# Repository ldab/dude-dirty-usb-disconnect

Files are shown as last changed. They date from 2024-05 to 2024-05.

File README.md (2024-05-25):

# dude-dirty-usb-disconnect







<p align="center">
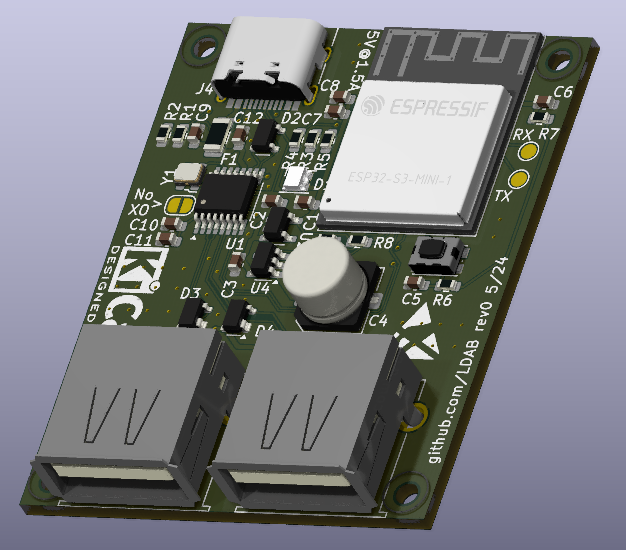
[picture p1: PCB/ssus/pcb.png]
  
</p>

USB CDC-ACM uart like controlled USB Hub:

- 1.5A fuse;
- Power switch with overcurrent, undervoltage and overtemperature protection;
- ESD Protection diodes on the USB lines;

## Todo

- [ ] WebBle
- [ ] Web flasher, like: https://esphome.github.io/esp-web-tools/ (does it work over CDC?)
- [ ] Get a PID from https://pid.codes/howto/ (only found how to change TinyUSB PID)
- [ ] There is some overflow around the help print for the `hub_settings`
- [ ] 3D printed case
- [x] `sdkconfig.default` for release with CDC (no jtag)

## Why?

I needed something to remotely disconnect and reconnect an USB device from my workstation, aka managed USB hub, the commercially available options where either [expensive](https://www.usbgear.com/managed-hubs.html) or needed [drivers](https://www.yepkit.com/products/ykush). So the idea here is an device that does not need external power and works as a USB CDC-ACM and one can simply send `hub_ports_off` over the terminal to turns the USB ports off.

## How?

As per USB-C [standard](https://www.usb.org/sites/default/files/USB%20Type-C%20Spec%20R2.0%20-%20August%202019.pdf), if you are bored read section 4.6.2.1, an USB-C source device should at least source 1.5A, as it is written:

  > All exposed USB Type-C Current ports shall have the ability to offer the same power capabilities. 
  > - All ports shall initially offer 1.5 A.

With that being said we can use the HUB with USB2.0 devices (500mA) with no problems. The device monitor the CC pins and it can detect if the source is able to provide the minimum required current (1.5A):

<p align="center">
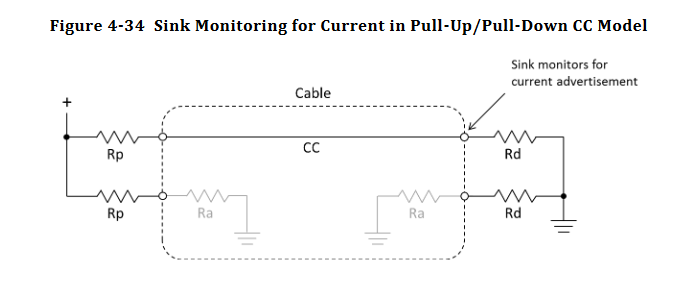
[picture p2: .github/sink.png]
  
</p>

**Table 4-36** indicates that a minimum of 0.7V should be read on CC for a 1.5A capable source, so we should be good with a USB-C to USB-C cable.

If you have an old laptop like me and it does not have an USB-C port, one can override the source check and send `hub_setings override_cc 1` and the HUB ports will be enabled even if the source does not provide enough power. On that case you may experience some weirdness on the final USB device, but hey, if you are here, you should have some idea of what you are doing.

One can also issue `hub_status` and see what the status is, for example:

```
dirty_usb_disconnect> hub_status
FW version: v0.0.1a
Hub is: Enabled
Fault: None
USB Host does not provide 1.5A
```

The CDC-ACM USB driver is based on espressif [example](https://github.com/espressif/esp-idf/tree/v5.2.1/examples/system/console/basic), you will find how it works there... the PID is 0x303A and VID is 0x0009. In case you are building the `debug` version the output will be over the USB-JTAG controller, PID:VID 0x303A:0x1001 (here you can also debug over USB, cool :smile:)

<p align="center">
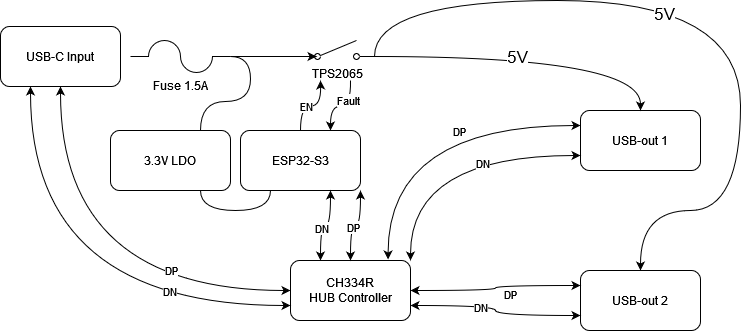
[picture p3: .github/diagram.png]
  
</p>

## Firmware

### Available commands

* Type `help` on the terminal

### LED

* Blue - idle, ports off;
* Green - ports on;
* Red - fault;

## Hardware 

- 1.5A fuse;
- [TPS2065C](https://www.ti.com/product/TPS2065C): 1A load, 86mΩ USB power switch with overcurrent, undervoltage and overtemperature protection;
- Device itself draws ~40mA;

<p align="center">
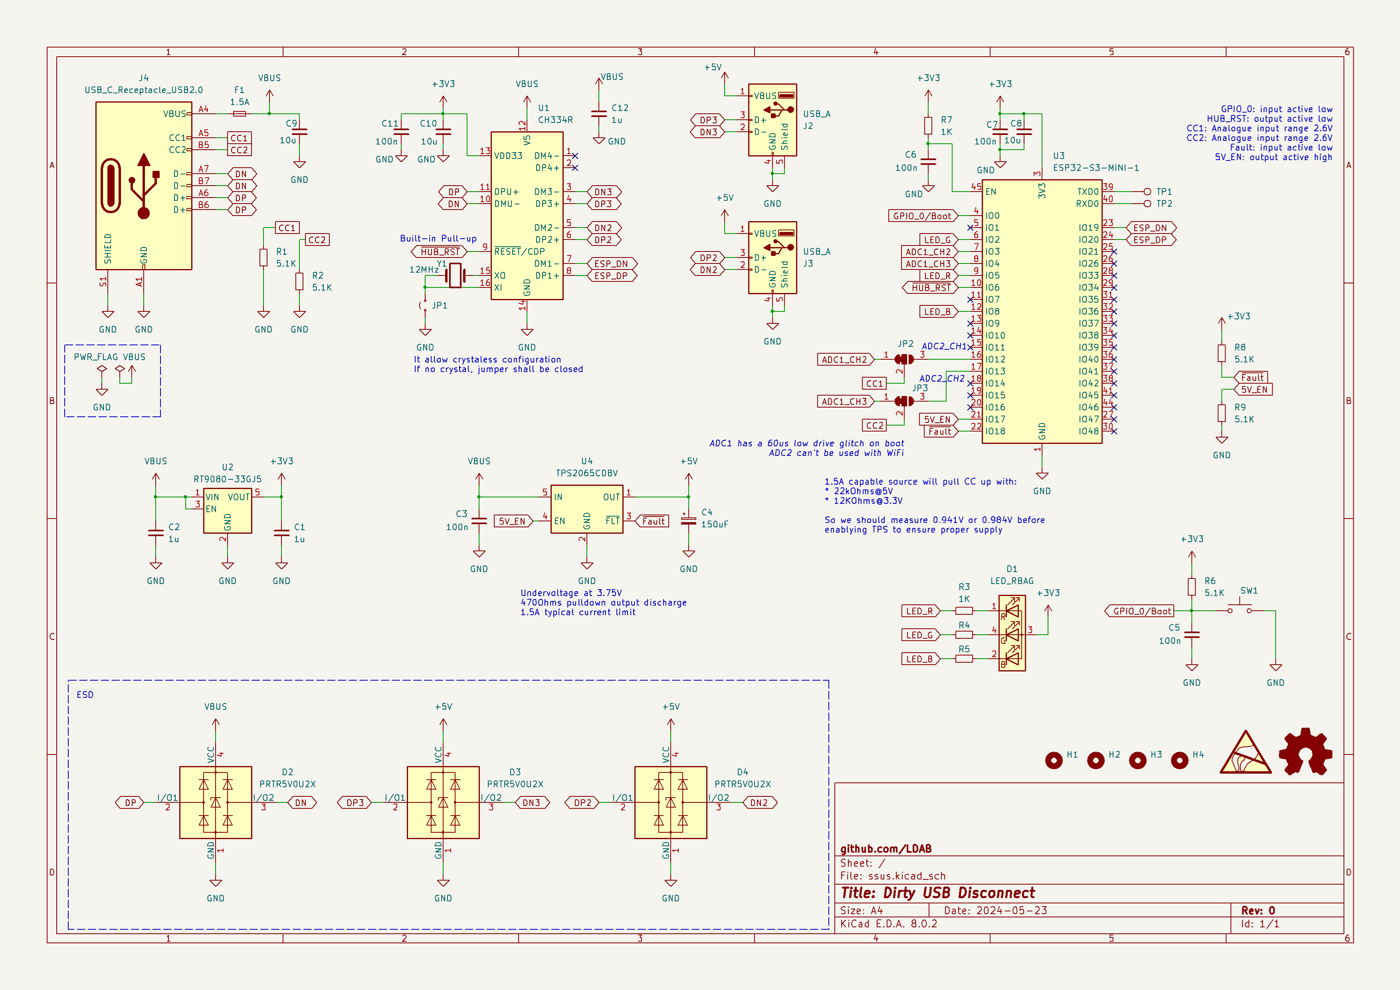
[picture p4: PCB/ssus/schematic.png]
  
</p>

- On the boards I made I changed all the resistors to 5.1KOhms for simplicity, the schematic did not update;
- Jumper 1 allows to use the HUB without crystal, saving 0.05USD :smile:;
- Jumper 2 and 3 changes the ADC to channel 2 as the channel 1 has a boot glitch (it should be ok). Bear in mind that ADC2 does not work with WiFi (rtfm);

## Note

- The hub controller datasheet indicates a internal pullup on RST, but it seems something is going on there, so next revision needs an external pull up, for now: https://github.com/ldab/dude-dirty-usb-disconnect/blob/4d217c8b5ad06fc77f75e4162ce3a6a554248eb0/components/app_hub_control/app_hub_control.c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

## Outro

- Some 3D models from: www.3dcontentcentral.com

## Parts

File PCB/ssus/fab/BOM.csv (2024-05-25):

Reference | Value | Footprint | Qty | LCSC | DNP
C1,C2,C12 | 1u | Capacitor_SMD:C_0603_1608Metric | 3 | C1592
C3,C5,C6,C7,C11 | 100n | Capacitor_SMD:C_0603_1608Metric | 5 | C338036
C4 | 150uF | Capacitor_SMD:C_Elec_6.3x5.4 | 1 | C2895744
C8,C9,C10 | 10u | Capacitor_SMD:C_0603_1608Metric | 3 | C87152
D1 | LED_RBAG | LED_SMD:LED_Cree-PLCC4_2x2mm_CW | 1 | C108793
D2,D3,D4 | PRTR5V0U2X | Package_TO_SOT_SMD:SOT-143 | 3 | C12333
F1 | 1.5A | Fuse:Fuse_1206_3216Metric | 1 | C89655
J2,J3 | USB_A | Connector_USB:USB_A_TE_292303-7_Horizontal | 2 | C42641
J4 | USB_C_Receptacle_USB2.0 | Connector_USB:USB_C_Receptacle_HRO_TYPE-C-31-M-12 | 1 | C319148
JP1 | 2 | Jumper:SolderJumper-2_P1.3mm_Open_RoundedPad1.0x1.5mm | 1
R1,R2,R6,R8,R9 | 5.1K | Resistor_SMD:R_0603_1608Metric | 5 | C14677
R3,R4,R5,R7 | 1K | Resistor_SMD:R_0603_1608Metric | 4 | C384295
SW1 | SW_Push | Button_Switch_SMD:SW_Push_1P1T_NO_CK_KMR2 | 1 | C128941
TP1,TP2 | TestPoint | TestPoint:TestPoint_Pad_D1.5mm | 2
U1 | CH334R | Package_SO:QSOP-16_3.9x4.9mm_P0.635mm | 1 | C4154405
U2 | RT9080-33GJ5 | Package_TO_SOT_SMD:SOT-23-5 | 1 | C841192
U3 | ESP32-S3-MINI-1 | RF_Module:ESP32-S2-MINI-1 | 1 | C2913206
U4 | TPS2065CDBV | Package_TO_SOT_SMD:SOT-23-5 | 1 | C353882
Y1 | 12MHz | Oscillator:Oscillator_SMD_ECS_2520MV-xxx-xx-4Pin_2.5x2.0mm | 1 | C21714041

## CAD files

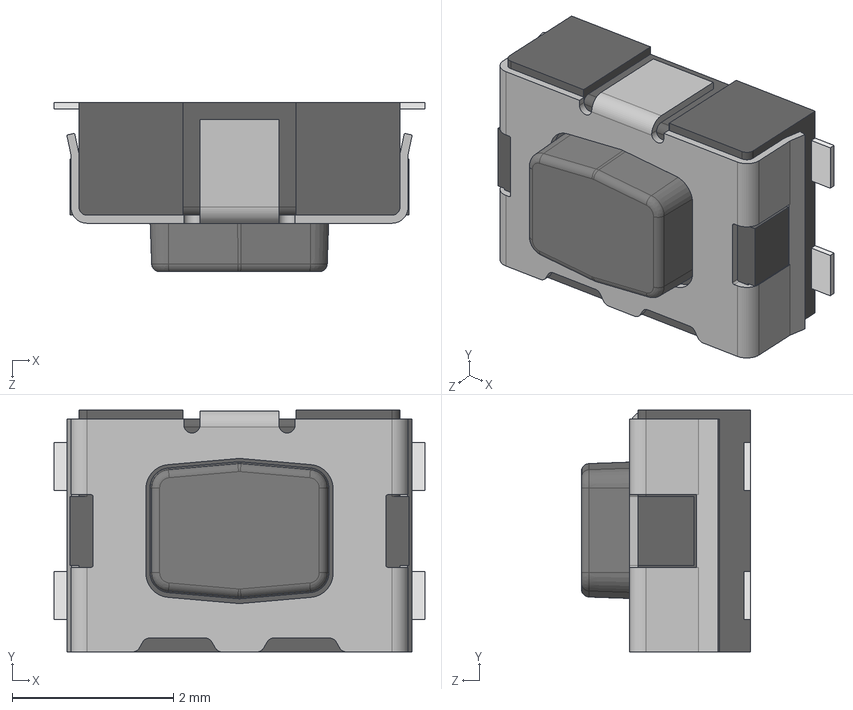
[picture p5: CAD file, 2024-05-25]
PCB/ssus/3D/User Library-Switch-CK-KMR2.STEP
4.60 x 3.00 x 2.10 mm
Button
Boitier
Tole
Pads

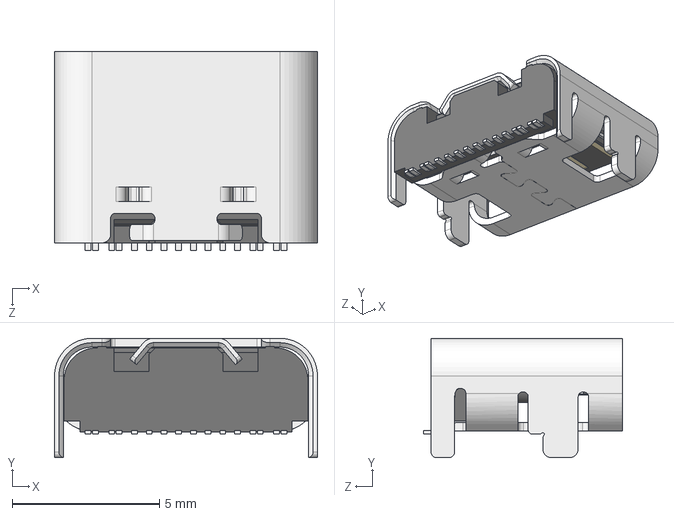
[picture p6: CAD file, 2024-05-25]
PCB/ssus/3D/User Library-GSB1C41X111DS1HR.STEP
8.94 x 4.06 x 6.75 mm

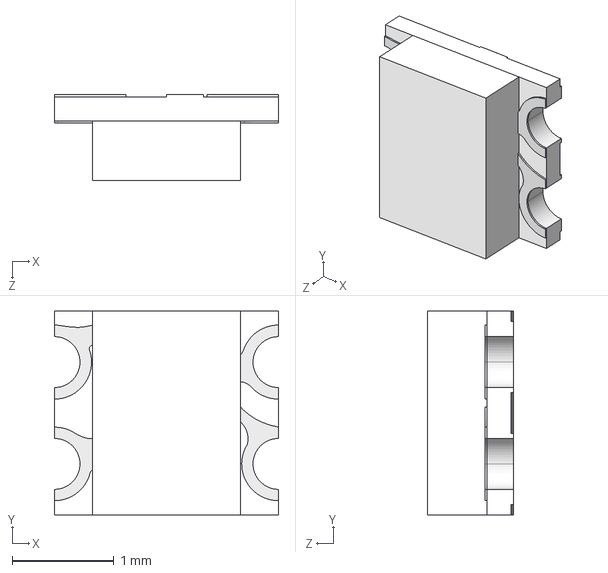
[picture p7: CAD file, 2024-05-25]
PCB/ssus/3D/User Library-WS2812-2020.STEP
2.20 x 2.00 x 0.84 mm

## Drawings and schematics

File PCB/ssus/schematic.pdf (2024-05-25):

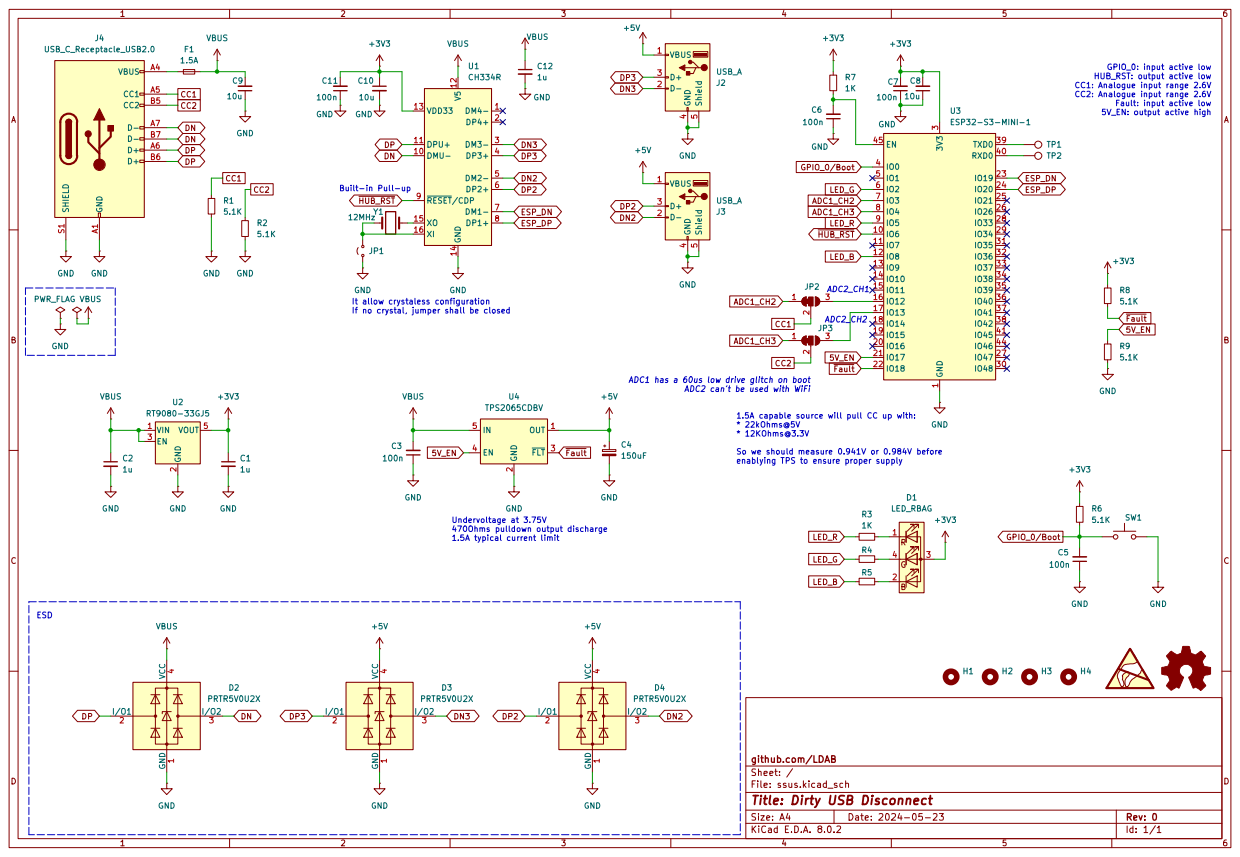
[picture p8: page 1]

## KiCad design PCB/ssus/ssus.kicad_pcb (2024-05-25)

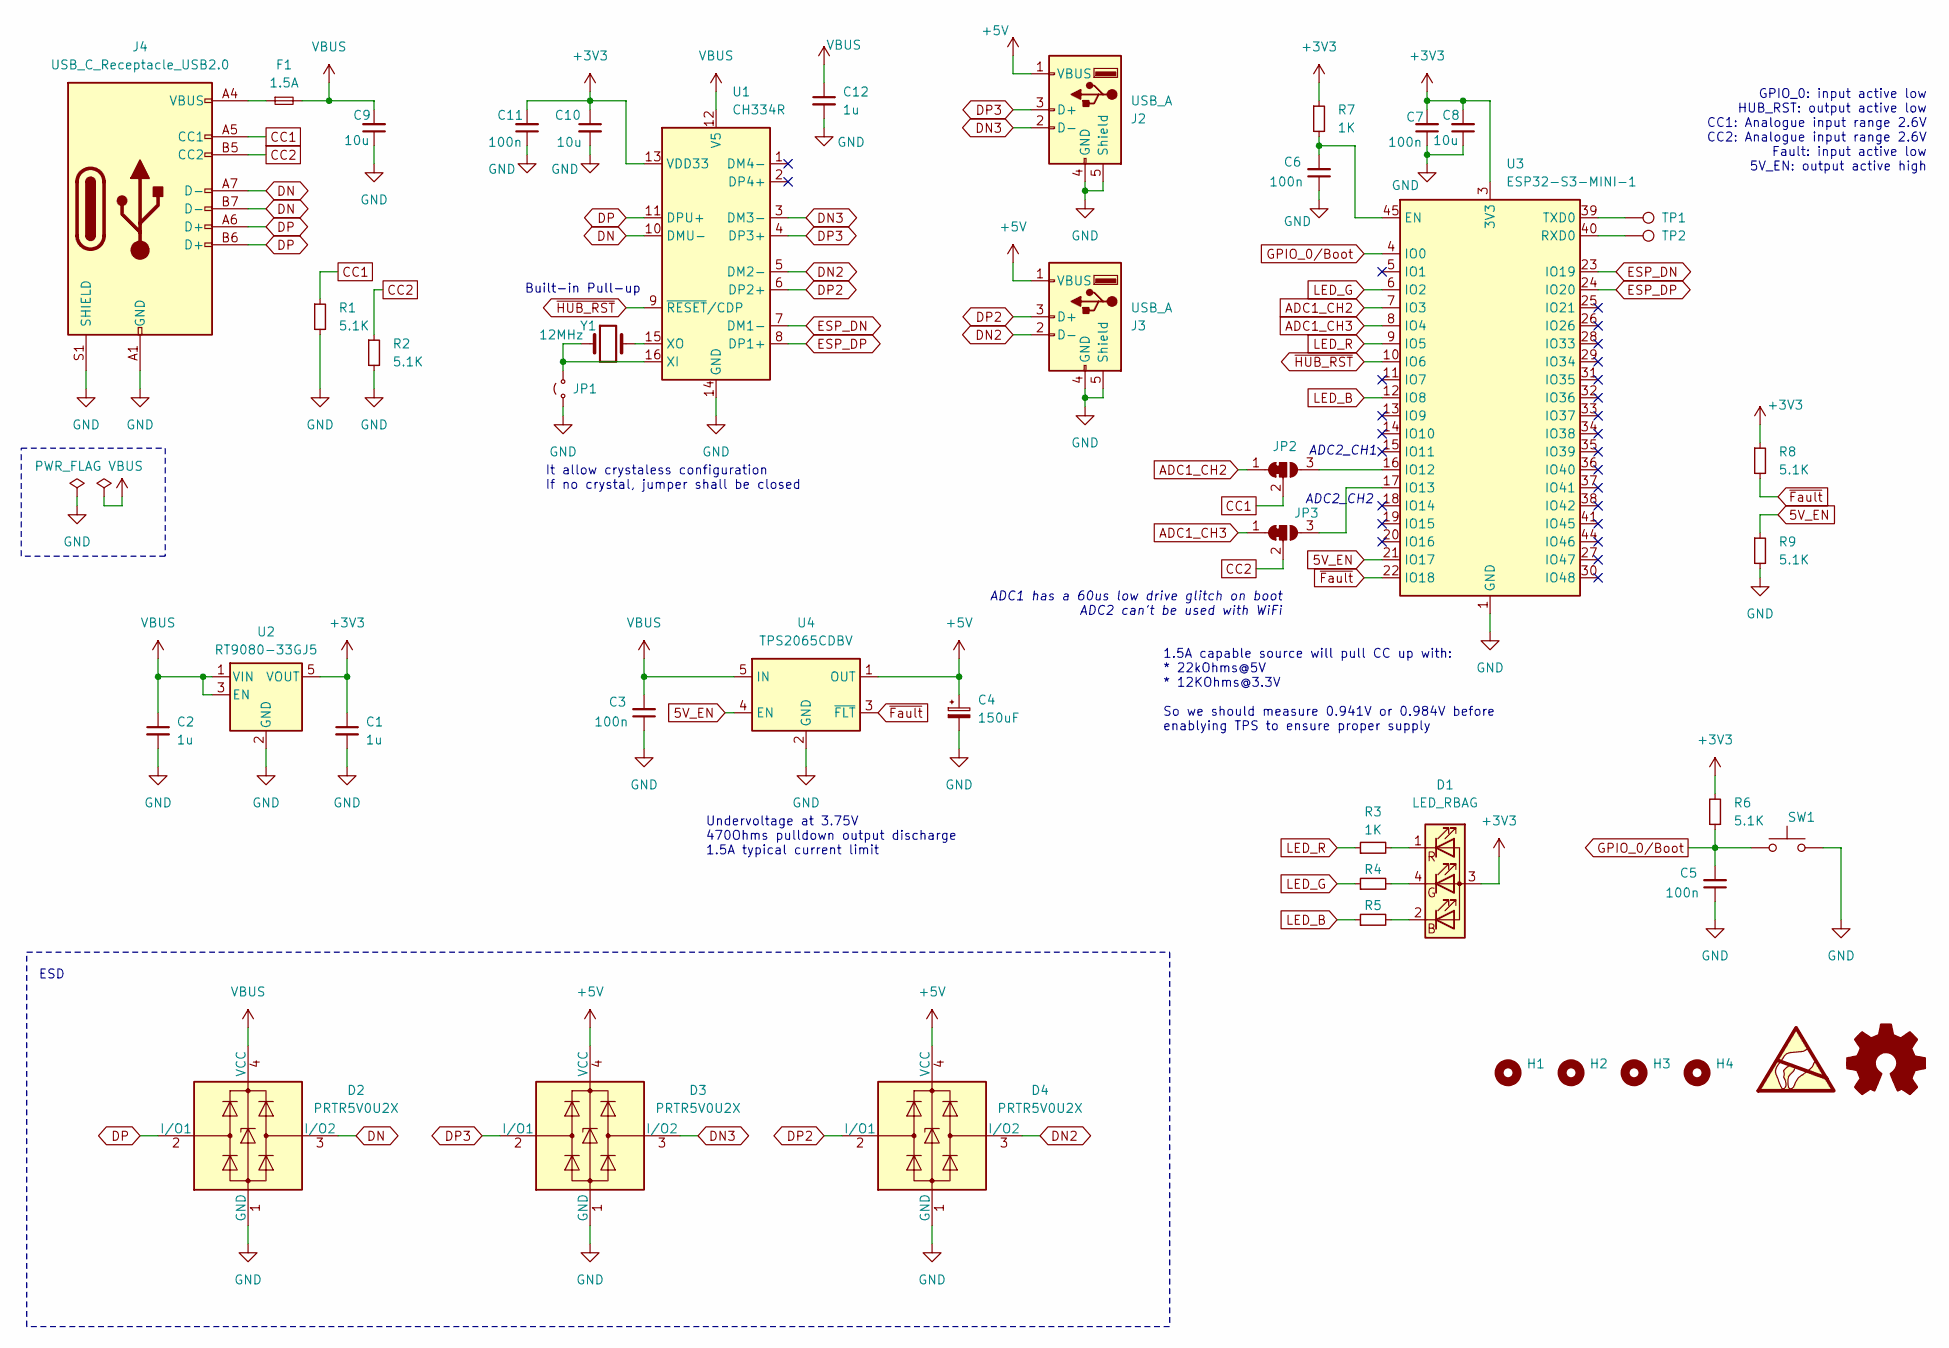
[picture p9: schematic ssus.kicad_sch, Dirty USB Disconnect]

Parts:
C1, C2, C12: 1u; C_0603_1608Metric; LCSC C1592
C3, C5, C6, C7, C11: 100n; C_0603_1608Metric; LCSC C338036
C4: 150uF; C_Elec_6.3x5.4; LCSC C2895744
C8, C9, C10: 10u; C_0603_1608Metric; LCSC C87152
D1: LED_RBAG; LED_Cree-PLCC4_2x2mm_CW; LCSC C108793
D2, D3, D4: PRTR5V0U2X; SOT-143; LCSC C12333
F1: 1.5A; Fuse_1206_3216Metric; LCSC C89655
H1, H2, H3, H4: MountingHole; MountingHole_2.1mm
J2, J3: USB_A; USB_A_TE_292303-7_Horizontal; LCSC C42641
J4: USB_C_Receptacle_USB2.0; USB_C_Receptacle_HRO_TYPE-C-31-M-12; LCSC C319148
JP1: 2; SolderJumper-2_P1.3mm_Open_RoundedPad1.0x1.5mm
JP2, JP3: 3; SolderJumper-3_P1.3mm_Bridged12_RoundedPad1.0x1.5mm
R1, R2, R6, R8, R9: 5.1K; R_0603_1608Metric; LCSC C14677
R3, R4, R5, R7: 1K; R_0603_1608Metric; LCSC C384295
SW1: SW_Push; SW_Push_1P1T_NO_CK_KMR2; LCSC C128941
TP1, TP2: TestPoint; TestPoint_Pad_D1.5mm
U1: CH334R; QSOP-16_3.9x4.9mm_P0.635mm; LCSC C4154405
U2: RT9080-33GJ5; SOT-23-5; LCSC C841192
U3: ESP32-S3-MINI-1; ESP32-S2-MINI-1; LCSC C2913206
U4: TPS2065CDBV; SOT-23-5; LCSC C353882
Y1: 12MHz; Oscillator_SMD_ECS_2520MV-xxx-xx-4Pin_2.5x2.0mm; LCSC C21714041

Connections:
5V_EN: R9.1, U3.21 (IO17), U4.4 (EN)
+3V3: C1.1, C7.2, C8.2, C10.1, C11.2, D1.3 (A), R6.2, R7.1, R8.1, U1.13 (VDD33), U2.5 (VOUT), U3.3 (3V3)
+5V: C4.1, D3.4 (VCC), D4.4 (VCC), J2.1 (VBUS), J3.1 (VBUS), U4.1 (OUT)
ADC1_CH2: JP2.1 (A), U3.7 (IO3)
ADC1_CH3: JP3.1 (A), U3.8 (IO4)
CC1: J4.A5 (CC1), JP2.2 (C), R1.1
CC2: J4.B5 (CC2), JP3.2 (C), R2.1
DN: D2.3 (I/O2), J4.A7 (D-), J4.B7 (D-), U1.10 (DMU-)
DN2: D4.3 (I/O2), J3.2 (D-), U1.5 (DM2-)
DN3: D3.3 (I/O2), J2.2 (D-), U1.3 (DM3-)
DP: D2.2 (I/O1), J4.A6 (D+), J4.B6 (D+), U1.11 (DPU+)
DP2: D4.2 (I/O1), J3.3 (D+), U1.6 (DP2+)
DP3: D3.2 (I/O1), J2.3 (D+), U1.4 (DP3+)
ESP_DN: U1.7 (DM1-), U3.23 (IO19)
ESP_DP: U1.8 (DP1+), U3.24 (IO20)
GND: C1.2, C2.2, C3.1, C4.2, C5.1, C6.1, C7.1, C8.1, C9.1, C10.2, C11.1, C12.2, D2.1 (GND), D3.1 (GND), D4.1 (GND), J2.4 (GND), J2.5 (Shield), J3.4 (GND), J3.5 (Shield), J4.A1 (GND), J4.A12 (GND), J4.B1 (GND), J4.B12 (GND), J4.S1 (SHIELD), JP1.1 (A), R1.2, R2.2, R9.2, SW1.2, U1.14 (GND), U2.2 (GND), U3.1 (GND), U3.2 (GND), U3.42 (GND), U3.43 (GND), U3.46 (GND), U3.47 (GND), U3.48 (GND), U3.49 (GND), U3.50 (GND), U3.51 (GND), U3.52 (GND), U3.53 (GND), U3.54 (GND), U3.55 (GND), U3.56 (GND), U3.57 (GND), U3.58 (GND), U3.59 (GND), U3.60 (GND), U3.61 (GND), U3.62 (GND), U3.63 (GND), U3.64 (GND), U3.65 (GND), U4.2 (GND)
GPIO_0/Boot: C5.2, R6.1, SW1.1, U3.4 (IO0)
LED_B: R5.1, U3.12 (IO8)
LED_G: R4.1, U3.6 (IO2)
LED_R: R3.1, U3.9 (IO5)
unnamed: D1.2 (BK), R5.2
unnamed: D1.4 (GK), R4.2
unnamed: D1.1 (RK), R3.2
unnamed: F1.1, J4.A4 (VBUS), J4.A9 (VBUS), J4.B4 (VBUS), J4.B9 (VBUS)
unnamed: JP1.2 (B), U1.16 (XI), Y1.1
unnamed: JP2.3 (B), U3.16 (IO12)
unnamed: JP3.3 (B), U3.17 (IO13)
unnamed: U1.15 (XO), Y1.2
unnamed: C6.2, R7.2, U3.45 (EN)
unnamed: TP2.1, U3.40 (RXD0)
unnamed: TP1.1, U3.39 (TXD0)
VBUS: C2.1, C3.2, C9.2, C12.1, D2.4 (VCC), F1.2, U1.12 (V5), U2.1 (VIN), U2.3 (EN), U4.5 (IN)
~Fault: R8.2, U3.22 (IO18), U4.3 (~FLT)
~HUB_RST: U1.9 (~RESET/CDP), U3.10 (IO6)

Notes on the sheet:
GPIO_0: input active low HUB_RST: output active low CC1: Analogue input range 2.6V CC2: Analogue input range 2.6V Fault: input active low 5V_EN: output active high
ADC2_CH1
It allow crystaless configuration If no crystal, jumper shall be closed
ADC2_CH2
1.5A capable source will pull CC up with: * 22kOhms@5V * 12KOhms@3.3V So we should measure 0.941V or 0.984V before enablying TPS to ensure proper supply
Built-in Pull-up
ESD
Undervoltage at 3.75V 470Ohms pulldown output discharge 1.5A typical current limit
ADC1 has a 60us low drive glitch on boot ADC2 can't be used with WiFi

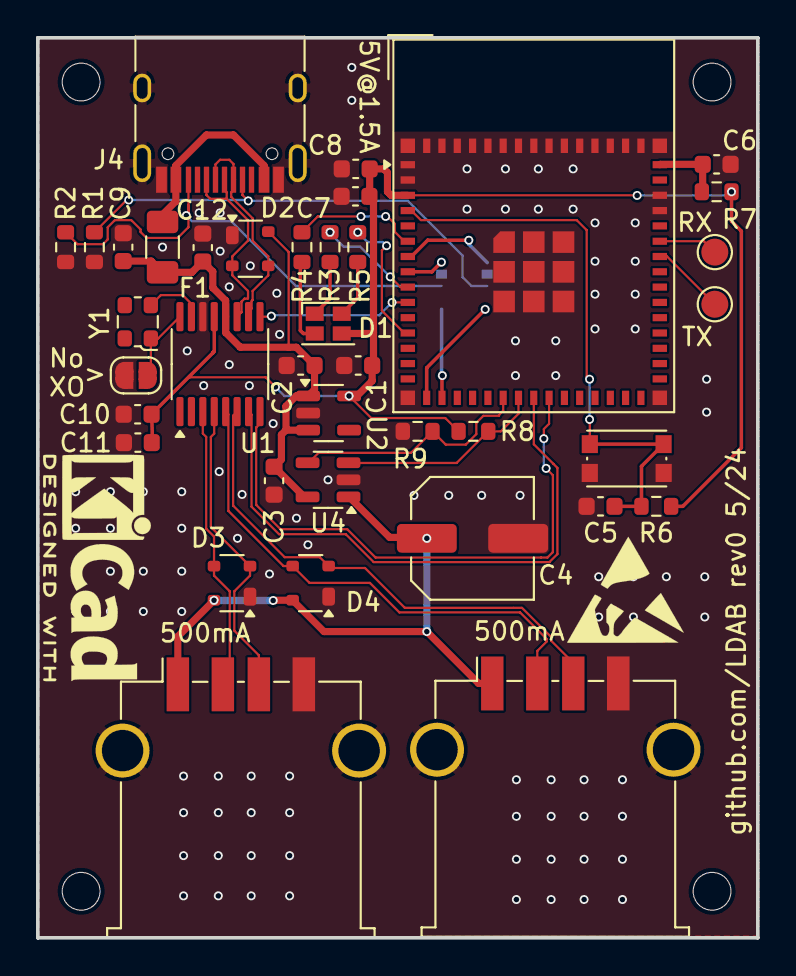
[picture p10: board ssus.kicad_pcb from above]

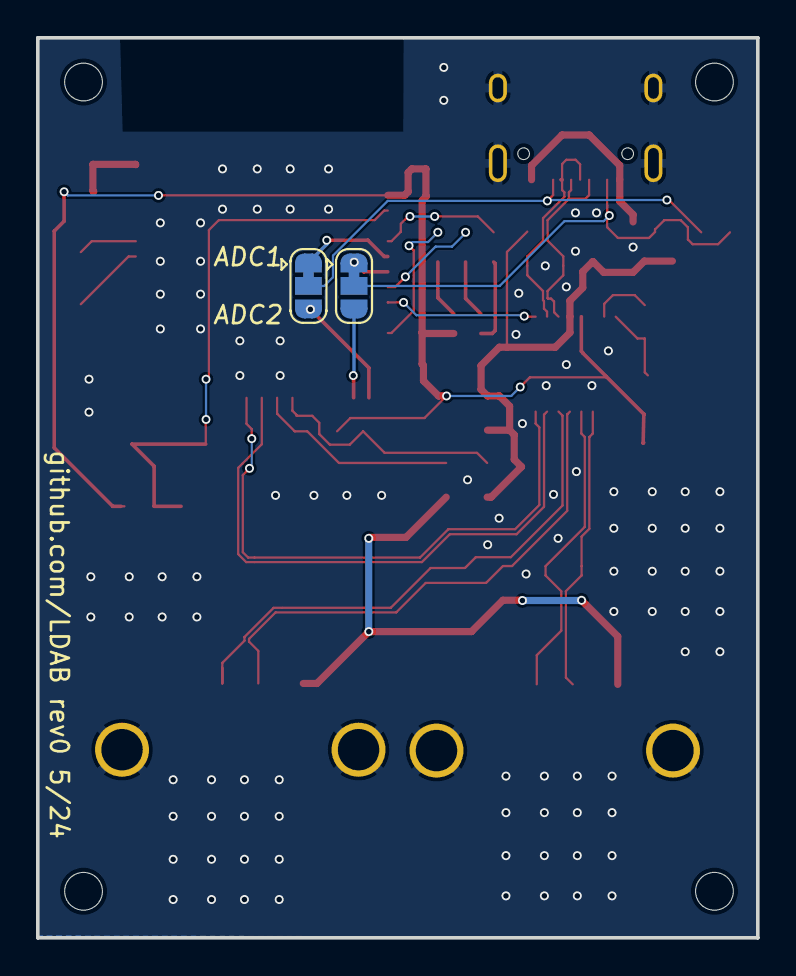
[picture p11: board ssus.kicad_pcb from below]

Board: 2 copper layers, 40.0 x 50.0 mm, 44 parts (2 on the bottom side), 34 nets.

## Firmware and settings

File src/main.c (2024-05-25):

#include "argtable3/argtable3.h"
#include "cmd_system.h"
// #include "cmd_nvs.h"
// #include "cmd_wifi.h"
#include "esp_app_desc.h"
#include "esp_console.h"
#include "esp_log.h"
#include "esp_system.h"
#include "esp_vfs_cdcacm.h"
#include "linenoise/linenoise.h"
#include "nvs.h"
#include "nvs_flash.h"
#include <fcntl.h>
#include <stdio.h>
#include <string.h>

#include "app_adc.h"
#include "app_hub_control.h"
#include "app_led.h"

static void initialize_nvs(void)
{
  esp_err_t err = nvs_flash_init();
  if (err == ESP_ERR_NVS_NO_FREE_PAGES || err == ESP_ERR_NVS_NEW_VERSION_FOUND) {
    ESP_ERROR_CHECK(nvs_flash_erase());
    err = nvs_flash_init();
  }
  ESP_ERROR_CHECK(err);
}

void app_main(void)
{
  char *prompt = calloc(strlen(esp_app_get_description()->project_name) + 2, sizeof(char));
  sprintf(prompt, "%s>", esp_app_get_description()->project_name);
  esp_console_repl_t *repl              = NULL;
  esp_console_repl_config_t repl_config = ESP_CONSOLE_REPL_CONFIG_DEFAULT();
  repl_config.max_cmdline_length        = 1024;
  repl_config.prompt                    = prompt;
  initialize_nvs();
  adc_init();
  app_led_start();

  /* Register commands */
  esp_console_register_help_command();
  register_system_common();
  // register_nvs();
  // register_wifi();
  register_hub_control();

#if defined(CONFIG_ESP_CONSOLE_USB_CDC)
  esp_console_dev_usb_cdc_config_t hw_config = ESP_CONSOLE_DEV_CDC_CONFIG_DEFAULT();
  ESP_ERROR_CHECK(esp_console_new_repl_usb_cdc(&hw_config, &repl_config, &repl));
#elif defined(CONFIG_ESP_CONSOLE_USB_SERIAL_JTAG)
  esp_console_dev_usb_serial_jtag_config_t hw_config = ESP_CONSOLE_DEV_USB_SERIAL_JTAG_CONFIG_DEFAULT();
  ESP_ERROR_CHECK(esp_console_new_repl_usb_serial_jtag(&hw_config, &repl_config, &repl));
#else
#error "no console defined"
#endif
  ESP_ERROR_CHECK(esp_console_start_repl(repl));

  free(prompt);
}

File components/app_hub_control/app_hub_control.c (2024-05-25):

#include <inttypes.h>
#include <stdio.h>
#include <string.h>

#include "argtable3/argtable3.h"
#include "assert.h"
#include "driver/gpio.h"
#include "esp_app_desc.h"
#include "esp_console.h"
#include "esp_log.h"
#include "freertos/FreeRTOS.h"
#include "freertos/task.h"
#include "nvs.h"
#include "nvs_flash.h"

#include "app_adc.h"
#include "app_hub_control.h"
#include "app_led.h"

#define HUB_RST   6
#define HUB_EN    17
#define HUB_FAULT 18
#define ON        1
#define OFF       0

#ifndef LOG_HUB_CONTROL_LEVEL
#define LOG_HUB_CONTROL_LEVEL ESP_LOG_WARN
#endif

// 1.5A capable source will pull CC up with:
// * 22kOhms@5V
// * 12KOhms@3.3V
// Table 4-36 says min 700mV for 1.5A
#define CC_1_5AMPS_CAPABLE_MV 700

typedef struct hub_setting {
  char *key;
  uint8_t val;
} hub_setting_t;

hub_setting_t hub_settings[] = {
    {
        .key = "override_cc",
        .val = false,
    },
    {
        .key = "auto_on",
        .val = true,
    },
};

static struct {
  struct arg_str *setting;
  struct arg_int *enable;
  struct arg_end *end;
} settings_args;

static const char *TAG                    = "app_hub_control";
static EventGroupHandle_t hub_event_group = NULL;
const static int FAULT_BIT                = BIT0;
const static int ON_CMD_BIT               = BIT1;
const static int OFF_CMD_BIT              = BIT2;
const static int STATUS_BIT               = BIT3;

static void save_config(hub_setting_t hub_setting);

static int hub_restart(int argc, char **argv)
{
  printf("Restarting USB HUB...\n");
  gpio_set_level(HUB_RST, OFF);
  vTaskDelay(pdMS_TO_TICKS(1000));
  gpio_set_level(HUB_RST, ON);

  return 0;
}

static int ports_off(int argc, char **argv)
{
  xEventGroupSetBits(hub_event_group, OFF_CMD_BIT);
  return 0;
}

static int ports_on(int argc, char **argv)
{
  xEventGroupSetBits(hub_event_group, ON_CMD_BIT);
  return 0;
}

static int port_restart(int argc, char **argv)
{
  printf("Restarting USB Ports...\n");
  ports_off(0, NULL);
  vTaskDelay(pdMS_TO_TICKS(1000));
  ports_on(0, NULL);

  return 0;
}

static int hub_status(int argc, char **argv)
{
  xEventGroupSetBits(hub_event_group, STATUS_BIT);
  return 0;
}

static int hub_settings_cmd(int argc, char **argv)
{
  int nerrors = arg_parse(argc, argv, (void **)&settings_args);
  if (nerrors != 0) {
    arg_print_errors(stderr, settings_args.end, argv[0]);
    return 1;
  }

  assert(settings_args.setting->count == 1);
  assert(settings_args.enable->count == 1);

  const hub_setting_t hub_setting = {
      .key = settings_args.setting->sval[0],
      .val = settings_args.enable->ival[0],
  };

  bool settings_exist = false;
  for (size_t i = 0; i < sizeof(hub_settings) / sizeof(hub_setting_t); i++) {
    if (strcmp(hub_setting.key, hub_settings[i].key) == 0) {
      settings_exist = true;
      break;
    }
  }

  if (!settings_exist) {
    printf("Setting %s is not valid!\n", hub_setting.key);
    return 1;
  }

  save_config(hub_setting);

  return 0;
}

static void register_hub_cmds(void)
{
  esp_console_cmd_t status_cmd = {
      .command = "hub_status",
      .help    = "HUB Controller Status",
      .hint    = NULL,
      .func    = &hub_status,
  };

  const esp_console_cmd_t restart_cmd = {
      .command = "hub_restart",
      .help    = "HUB Controller restart",
      .hint    = NULL,
      .func    = &hub_restart,
  };

  const esp_console_cmd_t ports_off_cmd = {
      .command = "hub_ports_off",
      .help    = "Turn USB Ports Off",
      .hint    = NULL,
      .func    = &ports_off,
  };

  const esp_console_cmd_t ports_on_cmd = {
      .command = "hub_ports_on",
      .help    = "Turn USB Ports On",
      .hint    = NULL,
      .func    = &ports_on,
  };

  const esp_console_cmd_t port_restart_cmd = {
      .command = "hub_port_restart",
      .help    = "HUB ports restart",
      .hint    = NULL,
      .func    = &port_restart,
  };

  uint32_t settings_options_size = 0;
  for (size_t i = 0; i < sizeof(hub_settings) / sizeof(hub_setting_t); i++) {
    settings_options_size += strlen(hub_settings[i].key) + 1; // add "|"
  }
  settings_options_size += 2; // null terminated + "<"
  char *settings_options = (char *)calloc(settings_options_size, sizeof(char));
  assert(settings_options != NULL);

  settings_options[0] = '<';
  for (size_t i = 0; i < sizeof(hub_settings) / sizeof(hub_setting_t); i++) {
    strcat(settings_options, hub_settings[i].key);
    strcat(settings_options, (i < (sizeof(hub_settings) / sizeof(hub_setting_t) - 1)) ? "|" : ">"); // last char
  }

  settings_args.setting                = arg_str1(NULL, NULL, (const char *)settings_options, "HUB setting");
  settings_args.enable                 = arg_int1(NULL, NULL, "<0|1>", "Enable (1) or disable (0) setting");
  settings_args.end                    = arg_end(2);
  const esp_console_cmd_t settings_cmd = {
      .command  = "hub_settings",
      .help     = "Set HUB settings, applied after restart!",
      .hint     = NULL,
      .func     = &hub_settings_cmd,
      .argtable = &settings_args,
  };

  ESP_ERROR_CHECK(esp_console_cmd_register(&status_cmd));
  ESP_ERROR_CHECK(esp_console_cmd_register(&restart_cmd));
  ESP_ERROR_CHECK(esp_console_cmd_register(&ports_off_cmd));
  ESP_ERROR_CHECK(esp_console_cmd_register(&ports_on_cmd));
  ESP_ERROR_CHECK(esp_console_cmd_register(&port_restart_cmd));
  ESP_ERROR_CHECK(esp_console_cmd_register(&settings_cmd));

  free(settings_options);
}

static void load_setting(hub_setting_t *hub_setting)
{
  nvs_handle_t nvs_handle;
  esp_err_t err = nvs_open("hub_settings", NVS_READWRITE, &nvs_handle);
  ESP_ERROR_CHECK(err);

  err = nvs_get_u8(nvs_handle, hub_setting->key, &hub_setting->val);
  ESP_ERROR_CHECK(err);

  nvs_close(nvs_handle);
  ESP_ERROR_CHECK(err);
}

static void load_config()
{
  nvs_handle_t nvs_handle;
  esp_err_t err = nvs_open("hub_settings", NVS_READWRITE, &nvs_handle);

  if (err != ESP_OK) {
    ESP_LOGE(TAG, "Error (%s) opening NVS handle!", esp_err_to_name(err));
  }

  ESP_ERROR_CHECK(err);

  for (size_t i = 0; i < sizeof(hub_settings) / sizeof(hub_setting_t); i++) {
    err = nvs_get_u8(nvs_handle, hub_settings[i].key, &hub_settings[i].val);
    switch (err) {
    case ESP_OK:
      ESP_LOGD(TAG, "Loaded %s setting: %d", hub_settings[i].key, hub_settings[i].val);
      break;
    case ESP_ERR_NVS_NOT_FOUND:
      ESP_LOGD(TAG, "NVS Settings is not initialized yet, do it now");
      err = nvs_set_u8(nvs_handle, hub_settings[i].key, hub_settings[i].val);
      ESP_ERROR_CHECK(err);
      err = nvs_commit(nvs_handle);
      ESP_ERROR_CHECK(err);
      break;
    default:
      ESP_LOGE(TAG, "Error (%s) reading!", esp_err_to_name(err));
    }
  }

  nvs_close(nvs_handle);
  ESP_ERROR_CHECK(err);
}
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

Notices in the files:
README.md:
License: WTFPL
